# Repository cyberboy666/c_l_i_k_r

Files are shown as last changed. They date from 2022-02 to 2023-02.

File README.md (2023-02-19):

# c_l_i_k_r
a [r_e_c_u_r](https://github.com/cyberboy666/r_e_c_u_r) video sampler extension circuit - custom keypad & midi controller



- this circuit is distributed by __UNDERSCORES__ - _an open video hardware label_ : it is available to purchase - as a pcb, kit or assembled unit - at [underscores.shop](https://underscores.shop/c_l_i_k_r/)
- the schematic for the circuit can be found [here](/hardware/schematic.pdf)
- the pcb gerber files for the lastest version can be found [here](/hardware/gerber_latest.zip)
- interactive BOM is [here](https://htmlpreview.github.io/?https://github.com/cyberboy666/c_l_i_k_r/blob/main/hardware/bom/ibom.html)
- consider [donating](https://opencollective.com/underscores) to the underscores project to help us continue creating for the commons
## description

__NOTE__ : _c_l_i_k_r is an extension circuit for my existing raspberry pi project [r_e_c_u_r](https://github.com/cyberboy666/r_e_c_u_r) - although this circuit will function as a stand alone midi+keypad controller it is mainly intended to be used with r_e_c_u_r_

This is a custom controller designed to operate the rpi video instrument r_e_c_u_r. It uses an arduino pro-micro to send key-presses and midi values to the pi over usb

- 20x tac-switches for discrete control
- 4x knobs + 4x cv inputs for continuous control
- firmware can be configured to send midi messages or keyboard presses

## demo video

(https://videos.scanlines.xyz/w/5TracZESx6C4LqAozoKyDW)

### background

this is an extension circuit that aims to offer an alternative to using cheapo plastic numpads to control recur. when i first designed recur i decided to use [these](https://www.aliexpress.com/item/4000748567192.html) numpads from aliexpress. my main goals at the time were making the project as simple and accessable as possible. however over the last few years many people have had problems using (possible variations?) of these numpads and others. seemingly similar devices run conflicting firmware, different layout of keys on different versions, crashes, gross hacks needed in the code, partial working units, and many more frustrating problems that are impossible for me to debug without owning every differnet device. i am also aware of contributing to the consumption of ecologically and ethically problematic products by endorsing these devices..

alsonow that recur has evolved beyond just a sample-player, having continuous control over parameters (like shaders) is more important than it was before. still one of the best options is to use a korg-nano-kontrol or similar midi controller as this gives many faders to control effects with. however for people who dont have a nanokontrol or want to use it elsewhere in their setup, i have been thinking of a small cheap and simple alterative to using numpads

# documentation

this project is fully _open-source hardware_ - all the files required to build it are included in this repo for free. if you have the time and/or skill you can contribute back by collaborating on / testing new designs, improving these docs, making demo videos/other creative content etc. you can also support the project financially by [donating directing](https://opencollective.com/underscores), or purchasing through the [web shop](https://underscores.shop).

depending on whether you are going fully diy or buying an assembled and tested unit, some of the following guides will be relavent to you. the flow would be:

## ordering parts

<details><summary><b>parts sourcing guide (w/ notes on pcb fabracation )</b> - start here if you are building fully from scatch or have purchased a pcb</summary>

i try to source all the parts i can from either:
- [tayda](https://www.taydaelectronics.com/) ; cheaper for common parts like resistors etc, also good for mechanical parts like switches and buttons
- [mouser](https://www.mouser.de/) ; has lots more options, speciality video ic's, can sometimes cost more (free shipping on orders over 50euros)
- other ; ocationally there will be parts which will need to be sourced elsewhere - usaully either aliexpress, ebay or amazon etc...

take a look at the [full_bom](/hardware/bom/full_bom.csv) for this project to see where i am sourcing each part from

since the only part on this BOM from mouser is the pots it may not be worth doing an order only for these - you could replace these with tayda pots `A-5531 or `A-1850` instead - if you are happy with the shorter shaft length.
  
## import into tayda

- go to the [tayda quick order](https://www.taydaelectronics.com/quick-order/) and in bottom corner choose _add from file_
- select the file [tayda_bom.csv](./hardware/bom/tayda_bom.csv) in the BOM folder (you will have to download it first or clone this repo)
- after importing select _add to cart_
- __NOTE:__ the minimum value for resistors is 10, so you may need to modify these values to add to cart (or if they are already modified here you will need to see the  full_bom for actual part QTY) 

- OPTIONAL: it is a good idea to add some dip-ic sockets and 2.54pin headers/sockets to your tayda order if you dont have them around already
  
## import into mouser

- go to [mouser bom tool](https://nz.mouser.com/Bom/) and click _upload spreadsheet_
- select the file [mouser_bom.csv](./hardware/bom/mouser_bom.csv) in this folder (you will have to download it first or clone this repo), then _upload my spreadsheet_ and _next_
- ensure that __Mouser Part Number__ is selected in the dropdown above the first row, then _next_, _process_
- if everything looks correct can now put _add to basket_

## selecting to omit some parts
  
- you may not want to include the 4x CV inputs in your build. in this case the 4x jacks, 4x resistors and 8x diode can be omitted from build
- you can also omit the 4x pots if you only want to use c_l_i_k_r as a usb-keyboard (for example if you already have a midi controller to use with r_e_c_u_r)
  
# ordering pcbs

you can support this project by buying individual pcbs from the [shop](https://underscores.shop). if you would rather have pcbs fabricated from gerbers directly the file you need is [here](/hardware/gerber_latest.zip) 

- i get my pcbs fabricated from [jlcpcb](https://cart.jlcpcb.com/quote) - 5 is the minumum order per design
- upload the zip file with the `add gerber file` button
- the default settings are mostly fine - set the __PCB Qty__ and __PCB Color__ settings (you can check that the file looks correct with pcb veiwer)
- it may be best to combine orders with other pcbs you want to have fab'd since the shipping can cost more than the items - also orginising group buys is a good way to distribute the extra pcbs /costs 
  
i often use jlcpcb because they are reliable, cheap and give you an option of colours. remember though that the cheapest Chinese fab houses are not always the most ethical or environmently friendly - if you can afford it consider supporting local companies. 

</details>

## assembly guide

<details><summary><b>assembly guide</b> - start here if you have purchased a diy kit</summary>

## interactive BOM for build guiding

follow this link to view the [interactive BOM](https://htmlpreview.github.io/?https://github.com/cyberboy666/c_l_i_k_r/blob/main/hardware/bom/ibom.html)

## general solder advices

- remember to heat pad first (2-3seconds), then add solder, then continue to heat (1-2seconds)

- Checkout the web-comic [soldering is easy](https://mightyohm.com/files/soldercomic/FullSolderComic_EN.pdf) for more soldering advice

## general order of assembly

- in general while assembling i start placing resistors and capacitors first. placing 5 - 10 components at a time and then flipping the board to solder them and trim the legs etc.
- next i would do diodes, transistors and ic's - taking care that these are placed in the right direction (using a ic socket can be useful)
- finally i place the interface parts - rca jacks, power jack, pots and switches - make sure these have lots of solder on for structural stablity

## specific assembly advice

- start with the lowest to place components : resistors and diodes, then do the tact buttons

- if you want to be able to remove the pro-micro from the board you will need to solder header sockets to the board – otherwise can directly solder pro-micro header pins

- finally place and solder the pots and jacks.
  
</details>
  
## firmware guide

<details><summary><b>firmware guide</b> - for editing the code & flashing it to your micro-controller</summary>
  
## flashing firmware onto the micro-controller
  
if you have got a kit from the shop the default firmware will be pre-configured - still you probably will want to follow this so you can edit the code and update the mappings.
  
### install guide
  
all _underscores_ projects with micro-controllers use [platformio](https://platformio.org/) with [visual studio code](https://code.visualstudio.com/) to edit, flash and monitor the code.
  
- first download (and unzip) the code in this repo - easiest is [as a zip](https://github.com/cyberboy666/c_l_i_k_r/archive/refs/heads/main.zip) or you can clone using git if you are comfortable with this
- next download, install and open [visual studio code](https://code.visualstudio.com/#alt-downloads)
- now open the extension tab within vscode on left vertical menu (or press ctrl-shift-x) and search for `platformio` to install this extension
  


- connect the micro-controller to computer via usb, open the c_l_i_k_r software folder (ctrl-k ctrl-o) in vscode and find the _platformio_ commands (either in left vertical menu under _platformio_ or little tick/arrow symbols along bottom blue bar) - `PlatformIO: Upload` should flash the default code to your micro-controller
  

  
### mapping edit guide
  
coming soon
  
</details>
  
## operating guide
  
<details><summary><b>operating guide</b> - start here if you have purchased an assembled unit</summary>


 
By connecting _c_l_i_k_r_ to _r_e_c_u_r_ with a usb cable the pi should auto-detect it as a usb-keyboard – as with any recur controls you will need to connect the keyboard before booting to ensure key mapping is performed on boot.

If `MIDI_INPUT` is set to `usb` under the _r_e_c_u_r_ __user_input__ setting then it should auto-detect it as usb-midi-controller also.

If you wish to instead connect a different midi device while using _c_l_i_k_r_ as a keyboard try the `CYCLE_MIDI_PORT` action in __user_input__ settings

The default mapping outputs `channel0: cc0 – cc3` on the 4 knobs and cv inputs of _c_l_i_k_r_ – this can be customised by editing the _c_l_i_k_r_ firmware. Tact buttons do not send midi by default but this can be enabled also in the firmware

one thing to note is that the _c_l_i_k_r_ keyboard only sends _key_press_ commands, not any _key_release_ commands - for this reason "gated" presses will not work - if your __FN__ key is not working with c_l_i_k_r then make sure that __SETTINGS -> sampler -> FUNC_GATED == off__ (same for ACTION_GATED)

[sending key_release commands may be possible in a future firmware updates so let me know if this is important to you ! ]

## flashing firmware to micro-controller

if you have got a kit from the shop the default firmware will be pre-configured - still you can follow this guide so you can edit the code and update the firmware.
  
### install guide
  
all _underscores_ projects with micro-controllers use [platformio](https://platformio.org/) with [visual studio code](https://code.visualstudio.com/) to edit, flash and monitor the code.
  
- first download (and unzip) the code in this repo - easiest is [as a zip](https://github.com/cyberboy666/c_l_i_k_r/archive/refs/heads/main.zip) or you can clone using git if you are comfortable with this
- next download, install and open [visual studio code](https://code.visualstudio.com/#alt-downloads)
- now open the extension tab within vscode on left vertical menu (or press ctrl-shift-x) and search for `platformio` to install this extension
  


- connect the micro-controller to computer via usb, open the c_l_i_k_r software folder (ctrl-k ctrl-o) in vscode and find the _platformio_ commands (either in left vertical menu under _platformio_ or little tick/arrow symbols along bottom blue bar) - `PlatformIO: Upload` should flash the default code to your micro-controller
  


</details>

### more info

<details><summary><b>how the circuit works</b></summary>
  
[coming soon]
                                                                                                                             
</details>

<details><summary><b>contributing guide</b></summary>
  
if you would like to contribute back to these projects in some way but dont know how the best thing (for now) would be to reach out to me directly ( tim@cyberboy666.com or @cyberboy666 on scanlines forum) - i will be happy to help
  
</details>

## credits & more info

This circuit is distributed through UNDERSCORES – open video hardware label – visit [underscores.shop](https://underscores.shop) for more info

The pcb was designed using KICAD

Everything from gerbers, cad files, panels and documentation is freely available online and distributed under CC-BY-SA / open-source licenses – help us contribute to the commons !

Ask any questions or start discussions related to this project on the [scanlines.xyz](https://scanlines.xyz) forum – an online community space dedicated to diy av / electronic media art

You can contact me directly at tim (at) cyberboy666 (dot) com 
Please get in touch if you are interested in hosting a workshop !



Thanks to all the r_e_c_u_r users who inspire me to better this project! to Bastien Lavaud for circuit advice, always. To Ben Caldwell for project advice. To everyone who has or will contribute ♥♥♥

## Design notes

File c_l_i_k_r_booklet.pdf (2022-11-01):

### cyberboy666 & underscores.shop present a r_e_c_u_r video sampler extension circuit

# c_l_i_k_r

## custom keypad and midi controller

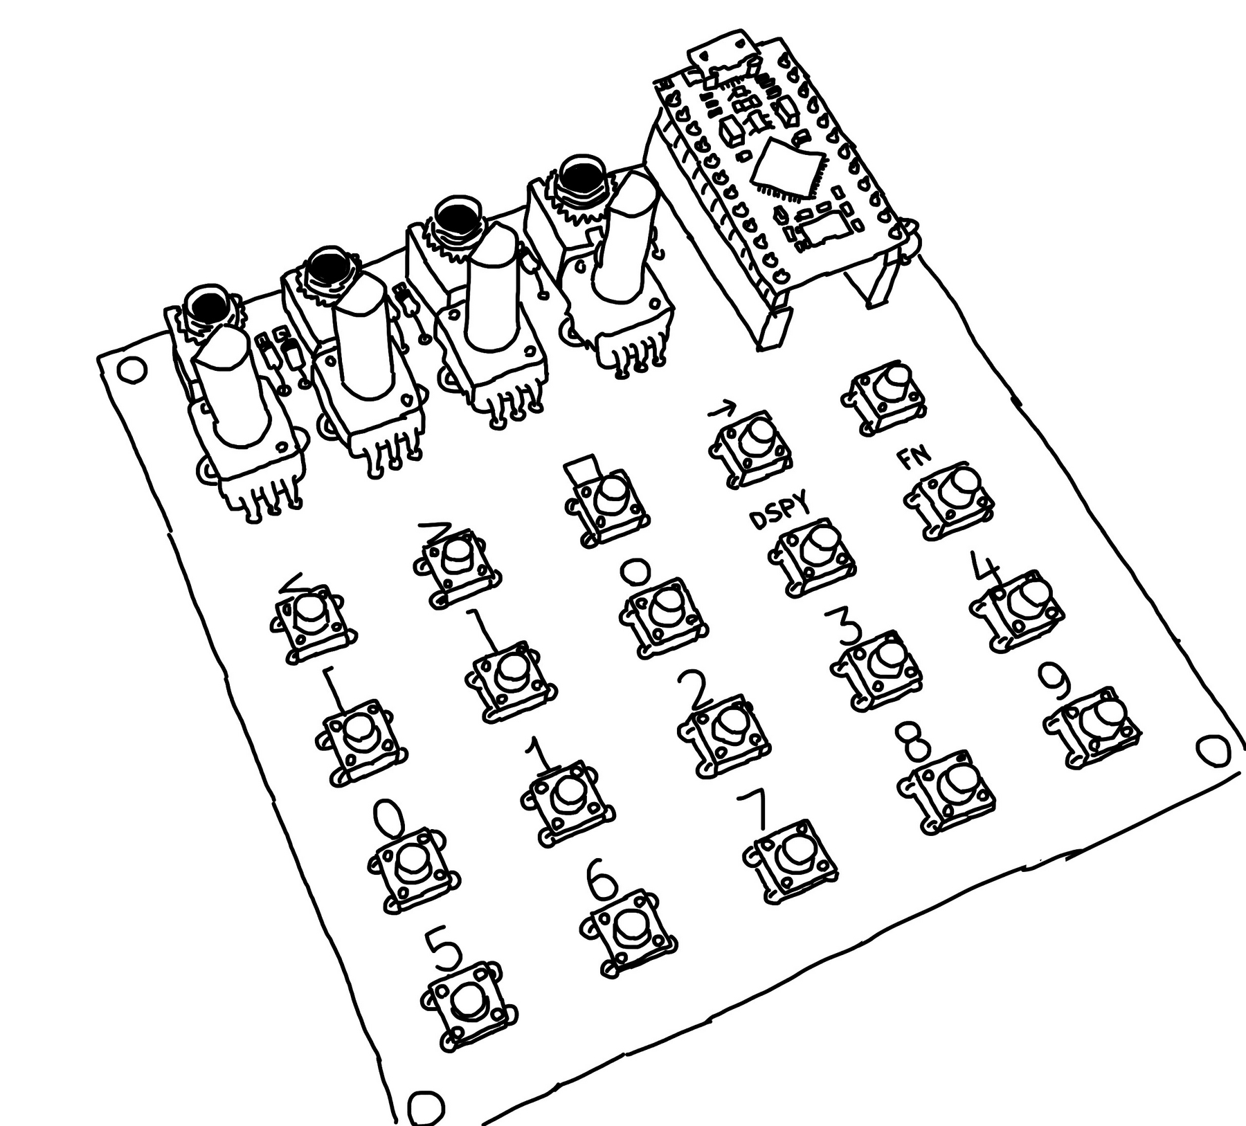
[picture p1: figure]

## instruction manual and build guide V0_2_1

View this project online at underscores.shop/c_l_i_k_r

# BACKGROUND

This is a custom controller designed to operate the rpi video instrument r_e_c_u_r. It uses an arduino pro-micro to send key-presses and midi values to the pi over usb:

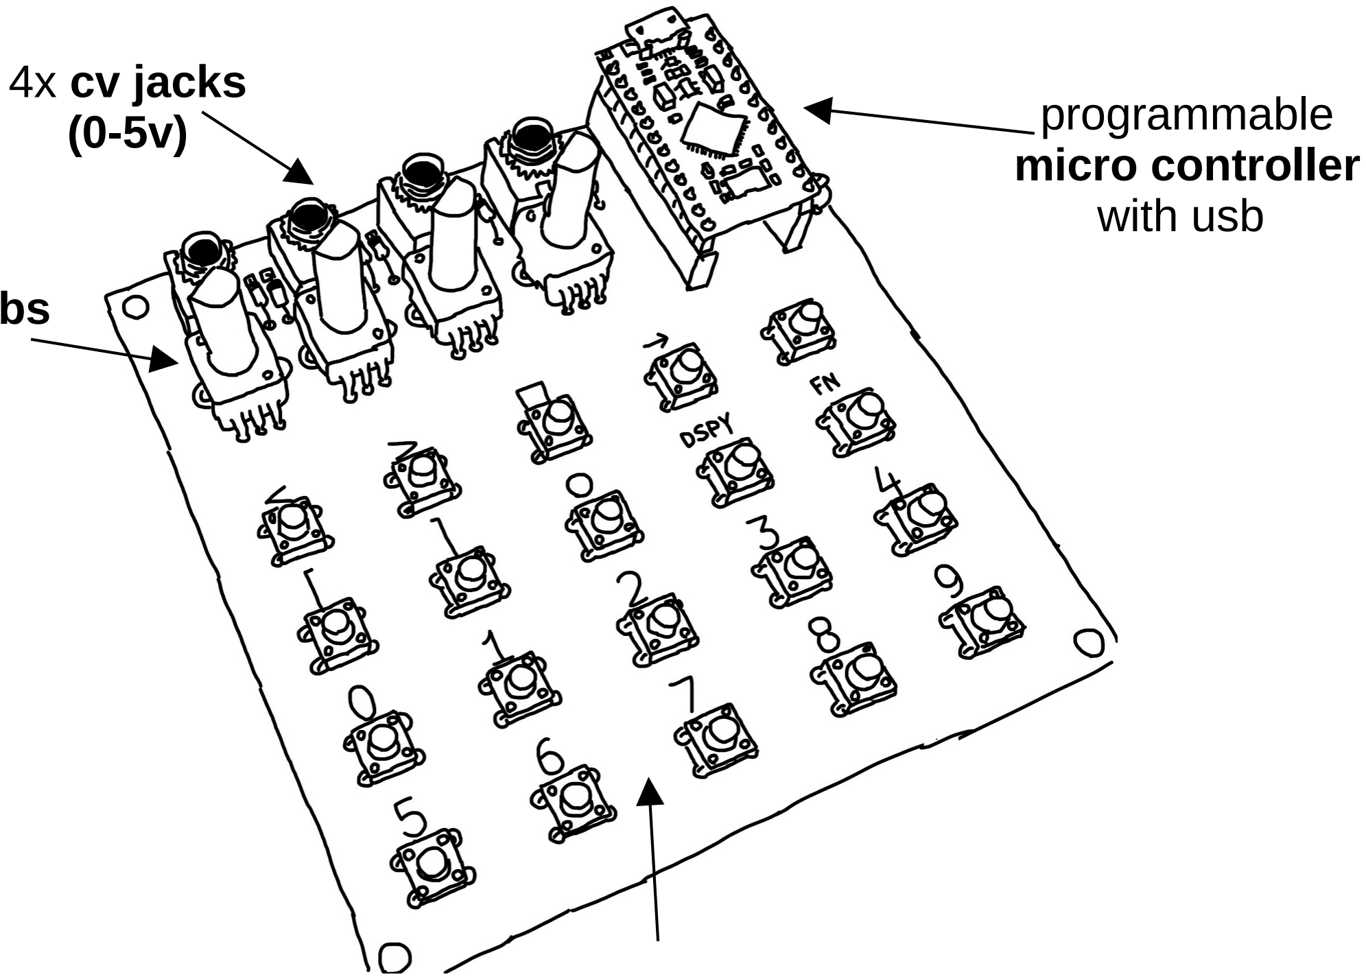
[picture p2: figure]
4x cv jacks; programmable; micro controller; with usb

- 20x tact buttons for discrete control over r_e_c_u_r
- 4x knobs for continuous control over r_e_c_u_r (eg shader parameters)
- 4x cv jacks (0-5v) for sequenced control over r_e_c_u_r (from older/analog synths eg eurorack)
- programmable micro controller with editable open-source firmware

20x tact buttons

4x knobs

## BUILD INSTRUCTIONS

Use the Interactive BOM to help place parts - kutt.it/IaYr8V

- remember to heat pad first (2-3seconds), then add solder, then continue to heat (1-2seconds) Checkout the web-comic soldering is easy for more soldering advice.
- start with the lowest components: resistors, diodes, tact buttons – take note of the direction on the diode - black bar on component matching black bar on footprint
- if you want to be able to remove the pro-micro from the board you will need to solder header sockets to the board – otherwise can directly solder pro-micro header pins
- finally place and solder the pots and jacks. be generous with the solder here -> this is to strengthen the mechanical connections as well as making electrical ones

## OPERATING GUIDE

Follow install instructions on the project page to edit and flash the firmware to your pro-micro

By connecting c_l_i_k_r to r_e_c_u_r with a usb cable the pi should auto-detect it as a usb-keyboard – same as with any recur control you need to connect the keyboard before booting to ensure key mapping is performed.

If MIDI_INPUT is set to usb under the r_e_c_u_r user_input settings then it should auto-detect it as usb-midi-controller also.

If you wish to instead connect a different midi device while using c_l_i_k_r as a keyboard try the CYCLE_MIDI_PORT action in settings

The default mapping outputs channel0: cc0 – cc3 on the 4 knobs and cv inputs of c_l_i_k_r – this can be customised by editing the c_l_i_k_r firmware. Tact buttons do not send midi by default but this can be enabled also in the firmware

Since c_l_i_k_r doesn’t currently send key_release commands you will need to turn off gated presses in r_e_c_u_r menu:
- settings → sampler → FUNC_GATED==off & ACTION_GATED==off

# CREDITS AND MORE INFO

This circuit is distributed through UNDERSCORES – open video hardware label – visit underscores.shop for more info

The pcb was designed using KICAD , this booklet was created in LibreOffice Draw

Everything from gerbers, cad files, panels and documentation is freely available online and distributed under CC-BY-SA / open-source licenses – help us contribute to the commons !

Ask any questions or start discussions related to this project on the scanlines.xyz forum – an online community space dedicated to diy av / electronic media art

You can contact me directly at tim (at) cyberboy666 (dot) com Please get in touch if you are interested in hosting a workshop !

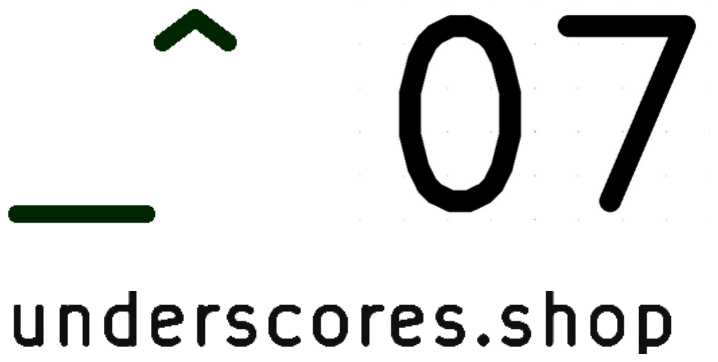
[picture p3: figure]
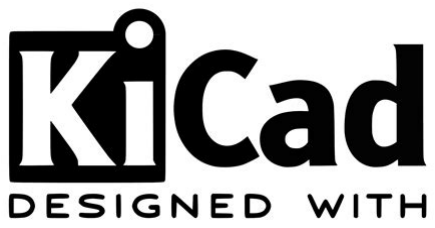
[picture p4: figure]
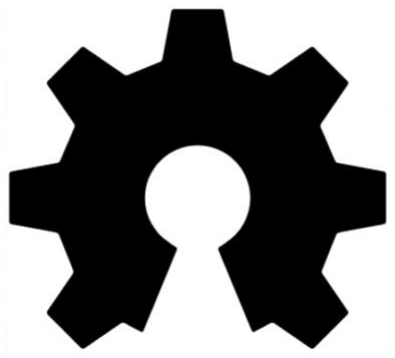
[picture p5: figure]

Thanks to all the r_e_c_u_r users who inspire me to better this project! to Bastien Lavaud for circuit advice, always. To Ben Caldwell for project advice. To everyone who has or will contribute ♥♥♥

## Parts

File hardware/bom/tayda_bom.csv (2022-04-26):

sku | qty | ref | val | vendor
A-1095 | 8 | D1 D2 D3 D4 D5 D6 D7 D8 | bat46 | tayda
A-2563 | 4 | J1 J2 J3 J4 | mono_jack_3.5mm | tayda
A-2200 | 4 | R1 R2 R3 R4 | 1k | tayda
A-5531 | 4 | RV1 RV2 RV3 RV4 | 10k_pot | tayda
A-5129 | 20 | SW1 SW2 SW3 SW4 SW5 SW6 SW7 SW8 SW9 SW10 SW11 SW12 SW13 SW14 SW15 SW16 SW17 SW18 SW19 SW20 | Push | tayda

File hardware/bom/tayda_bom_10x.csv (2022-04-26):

sku | qty | ref | val | vendor
A-1095 | 80 | D1 D2 D3 D4 D5 D6 D7 D8 | bat46 | tayda
A-2563 | 40 | J1 J2 J3 J4 | mono_jack_3.5mm | tayda
A-2200 | 40 | R1 R2 R3 R4 | 1k | tayda
A-5531 | 40 | RV1 RV2 RV3 RV4 | 10k_pot | tayda
A-5129 | 200 | SW1 SW2 SW3 SW4 SW5 SW6 SW7 SW8 SW9 SW10 SW11 SW12 SW13 SW14 SW15 SW16 SW17 SW18 SW19 SW20 | Push | tayda

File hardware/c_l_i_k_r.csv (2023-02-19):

Reference | Quantity | Value | Footprint | Datasheet
D1 D2 D3 D4 D5 D6 D7 D8 | 8 | bat46 | Diode_THT:D_DO-34_SOD68_P7.62mm_Horizontal
J1 J2 J3 J4 | 4 | mono_jack_3.5mm | Connector_Audio:Jack_3.5mm_QingPu_WQP-PJ398SM_Vertical_CircularHoles
R1 R2 R3 R4 | 4 | 1k | Resistor_THT:R_Axial_DIN0207_L6.3mm_D2.5mm_P7.62mm_Horizontal
RV1 RV2 RV3 RV4 | 4 | 10k_pot | Potentiometer_THT:Potentiometer_Alps_RK09L_Single_Vertical
SW1 SW2 SW3 SW4 SW5 SW6 SW7 SW8 SW9 SW10 SW11 SW12 SW13 SW14 SW15 SW16 SW17 SW18 SW19 SW20 | 20 | Push | Button_Switch_THT:SW_PUSH_6mm_H7.3mm
U1 | 1 | ProMicro | project_parts:tht_ProMicro

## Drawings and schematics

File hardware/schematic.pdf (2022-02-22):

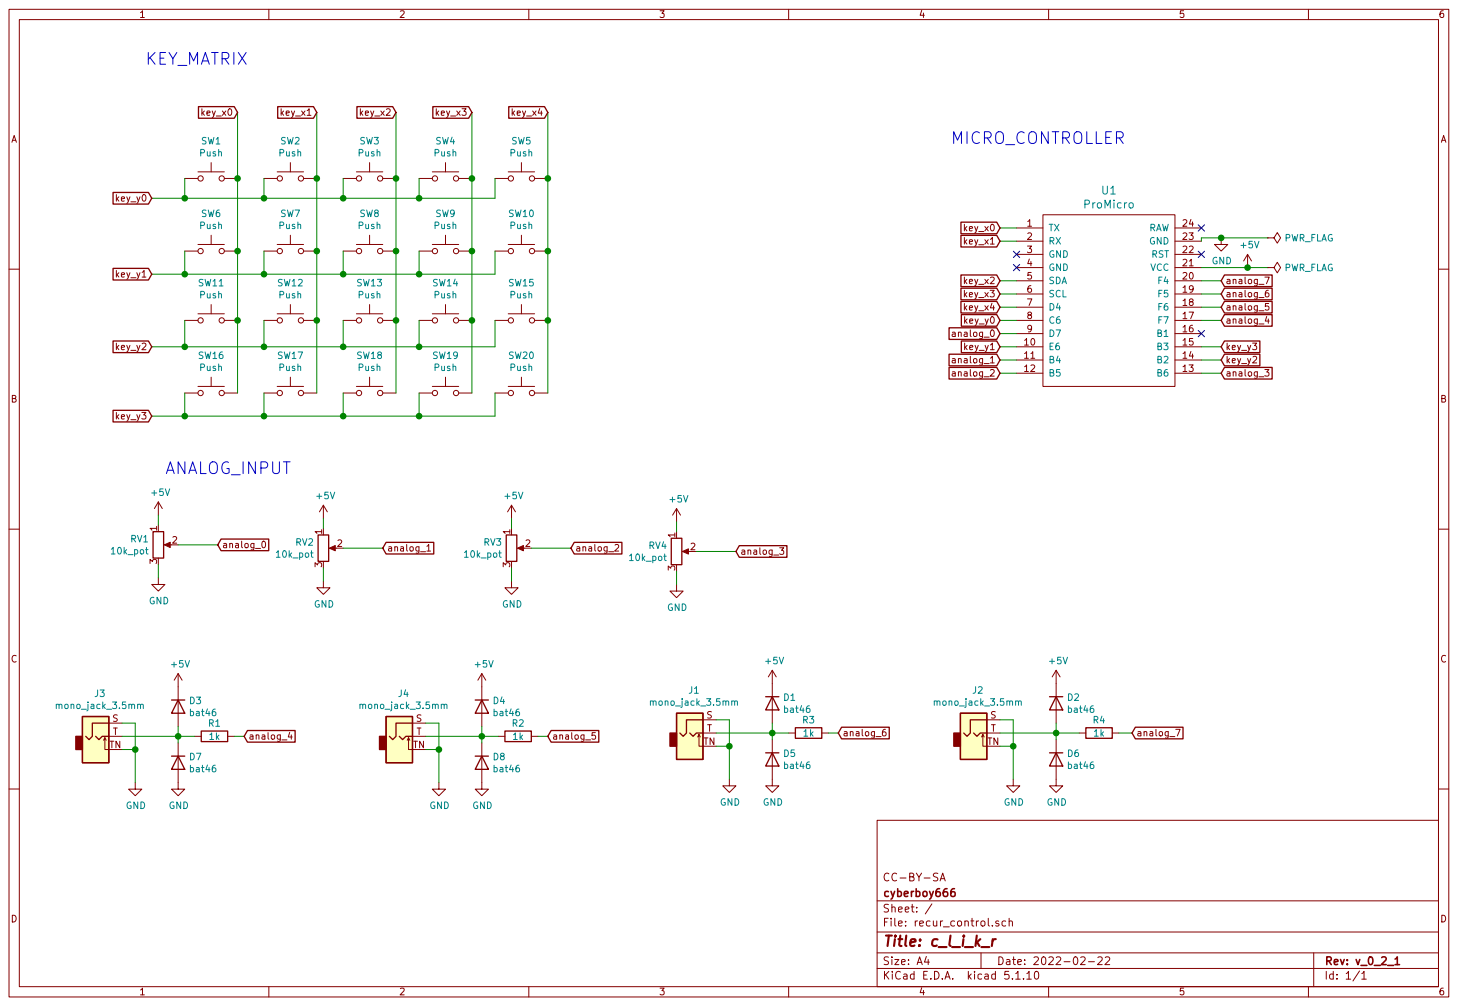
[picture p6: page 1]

File: recur_control.sch Sheet: / cyberboy666 CC-BY-SA

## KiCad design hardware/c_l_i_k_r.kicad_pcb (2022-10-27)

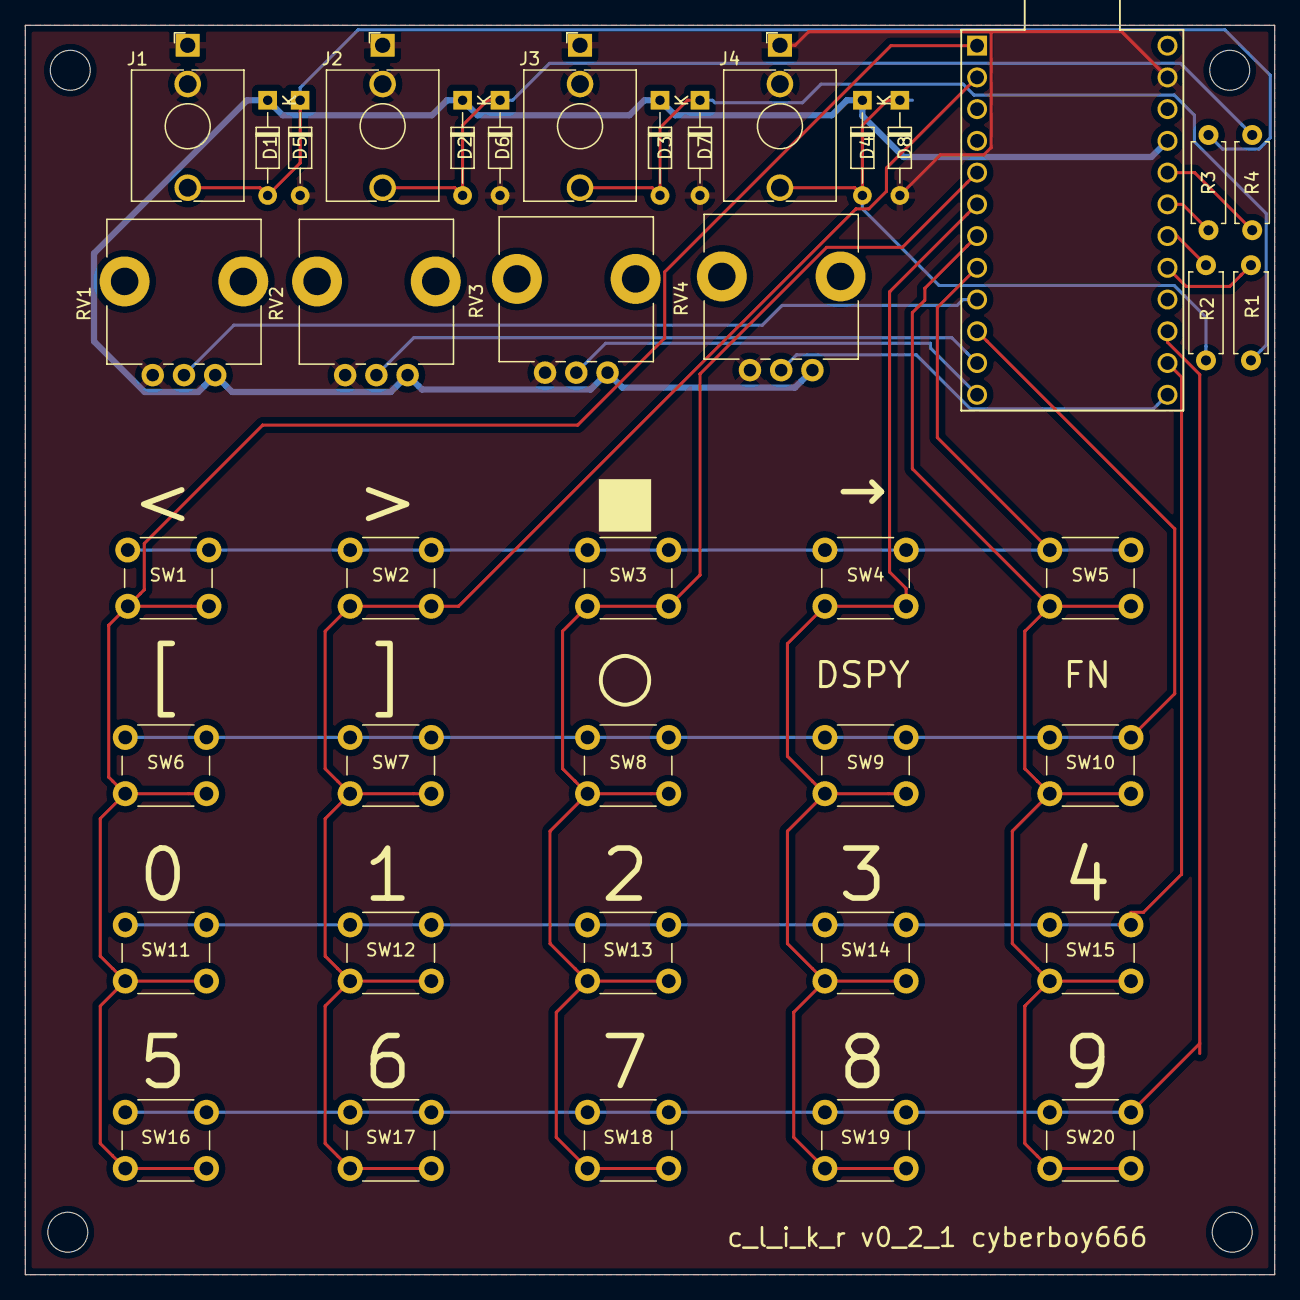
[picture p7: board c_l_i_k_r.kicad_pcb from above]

Board: 2 copper layers, 100.0 x 100.0 mm, 41 parts (0 on the bottom side), 23 nets.

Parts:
D1, D2, D3, D4, D5, D6, D7, D8: bat46; D_DO-34_SOD68_P7.62mm_Horizontal
J1, J2, J3, J4: mono_jack_3.5mm; Jack_3.5mm_QingPu_WQP-PJ398SM_Vertical_CircularHoles
R1, R2, R3, R4: 1k; R_Axial_DIN0207_L6.3mm_D2.5mm_P7.62mm_Horizontal
RV1, RV2, RV3, RV4: 10k_pot; Potentiometer_Alps_RK09L_Single_Vertical
SW1, SW2, SW3, SW4, SW5, SW6, SW7, SW8, SW9, SW10, SW11, SW12, SW13, SW14, SW15, SW16, SW17, SW18, SW19, SW20: Push; SW_PUSH_6mm_H7.3mm
U1: ProMicro

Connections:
+5V: D1.1, D2.1, D3.1, D4.1, RV1.1, RV2.1, RV3.1, RV4.1, U1.21
GND: D5.2, D6.2, D7.2, D8.2, J1.S, J1.TN, J2.S, J2.TN, J3.S, J3.TN, J4.S, J4.TN, RV1.3, RV2.3, RV3.3, RV4.3, U1.23
unnamed: D1.2, D5.1, J1.T, R3.2
unnamed: D2.2, D6.1, J2.T, R4.2
unnamed: D3.2, D7.1, J3.T, R1.2
unnamed: D4.2, D8.1, J4.T, R2.2
analog_0: RV1.2, U1.9
analog_1: RV2.2, U1.11
analog_2: RV3.2, U1.12
analog_3: RV4.2, U1.13
analog_4: R1.1, U1.17
analog_5: R2.1, U1.18
analog_6: R3.1, U1.19
analog_7: R4.1, U1.20
key_x0: SW1.2, SW6.2, SW11.2, SW16.2, U1.1
key_x1: SW2.2, SW7.2, SW12.2, SW17.2, U1.2
key_x2: SW3.2, SW8.2, SW13.2, SW18.2, U1.5
key_x3: SW4.2, SW9.2, SW14.2, SW19.2, U1.6
key_x4: SW5.2, SW10.2, SW15.2, SW20.2, U1.7
key_y0: SW1.1, SW2.1, SW3.1, SW4.1, SW5.1, U1.8
key_y1: SW6.1, SW7.1, SW8.1, SW9.1, SW10.1, U1.10
key_y2: SW11.1, SW12.1, SW13.1, SW14.1, SW15.1, U1.14
key_y3: SW16.1, SW17.1, SW18.1, SW19.1, SW20.1, U1.15

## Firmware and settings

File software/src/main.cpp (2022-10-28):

#include <Arduino.h>
#include <Keypad.h>
#include <Keyboard.h>
#include <usbmidi.h>

const byte ROWS = 4; //five rows
const byte COLS = 5; //four columns
char keys[ROWS][COLS] = {
  {'a', 'b', 'c', 'd', 'x'},
  {'e', 'f', 'g', 'h', 'i'},
  {'j', 'k', 'l', 'm', 'n'},
  {'o', 'p', 'q', 'r', 's'}
};
byte rowPins[ROWS] = {5, 7, 16, 14}; //connect to the row pinouts of the keypad
byte colPins[COLS] = {1, 0, 2, 3, 4}; //connect to the column pinouts of the keypad

Keypad keypad = Keypad( makeKeymap(keys), rowPins, colPins, ROWS, COLS );

int a0 = A7;
int a1 = A8;
int a2 = A9;
int a3 = A10;
int a4 = A2;
int a5 = A3;
int a6 = A0;
int a7 = A1;

int v0, v1, v2, v3, v4, v5, v6, v7;
int n0, n1, n2, n3, n4, n5, n6, n7;

void sendCC(uint8_t channel, uint8_t control, uint8_t value) {
  
	USBMIDI.write(0xB0 | (channel & 0xf));
	USBMIDI.write(control & 0x7f);
	USBMIDI.write(value & 0x7f);
  USBMIDI.flush();
}

void checkAndSendValue(int old_analog_value, int new_analog_value, uint8_t control) {
  if(old_analog_value != new_analog_value){
      sendCC(0,control,new_analog_value);
  }
}

void setup() {
  Serial.begin(9600);
  Keyboard.begin();

}

void loop() {
    v0 = analogRead(a0)/8;
    checkAndSendValue(n0, v0, 0);
    n0 = v0;
    v1 = analogRead(a1)/8;
    checkAndSendValue(n1, v1, 1);
    n1 = v1;
    v2 = analogRead(a2)/8;
    checkAndSendValue(n2, v2, 2);
    n2 = v2;
    v3 = analogRead(a3)/8;
    checkAndSendValue(n3, v3, 3);
    n3 = v3;
    v4 = analogRead(a4)/8;
    checkAndSendValue(n4, v4, 4);
    n4 = v4;
    v5 = analogRead(a5)/8;
    checkAndSendValue(n5, v5, 5);
    n5 = v5;
    v6 = analogRead(a6)/8;
    checkAndSendValue(n6, v6, 6);
    n6 = v6;
    v7 = analogRead(a7)/8;
    checkAndSendValue(n7, v7, 7);
    n7 = v7;

  char key = keypad.getKey();

  if (key != NO_KEY){
     Keyboard.write(key);
     Serial.write(key);
     }
}

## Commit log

2022-01-10 migrate to own repo
    [recur_control.kicad_pcb, recur_control.sch]
2022-02-22 update code and circuit revision
    [recur_control.kicad_pcb, recur_control.sch]
2022-02-22 rename kicad project
    [c_l_i_k_r.kicad_pcb, c_l_i_k_r.sch]
2022-02-28 update bom
    [c_l_i_k_r.csv, full_bom.csv, mouser_bom.csv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]
2022-10-27 made pot holes larger
    [c_l_i_k_r.kicad_pcb, c_l_i_k_r.kicad_sch]
